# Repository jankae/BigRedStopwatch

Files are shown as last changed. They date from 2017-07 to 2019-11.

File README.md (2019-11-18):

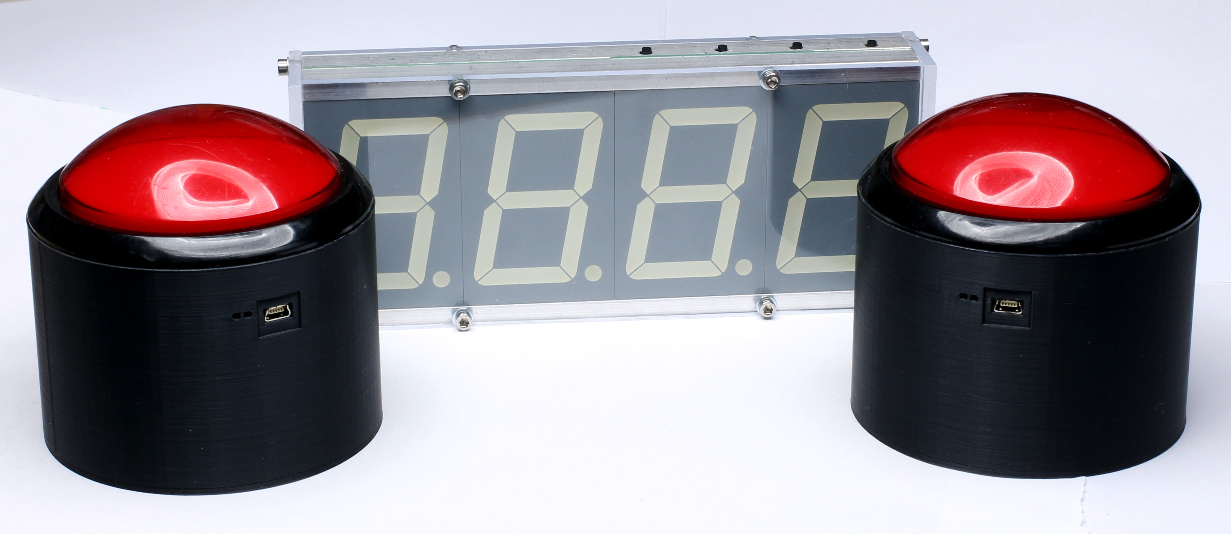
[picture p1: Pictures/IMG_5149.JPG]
Stopwatch

# What is it?
* A huge stopwatch with two big red control buttons (start and stop)
* Mainly intended for measuring time on an obstacle course

# How does it work?
* Each button and the display contain a radio module (RFM69)
* Button presses are send to the display which calculates the time

# Further features
* USB charging of the integrated LiPo batteries
* Retransmissions with time compensation if a radio packet gets lost
* Simple highscore management

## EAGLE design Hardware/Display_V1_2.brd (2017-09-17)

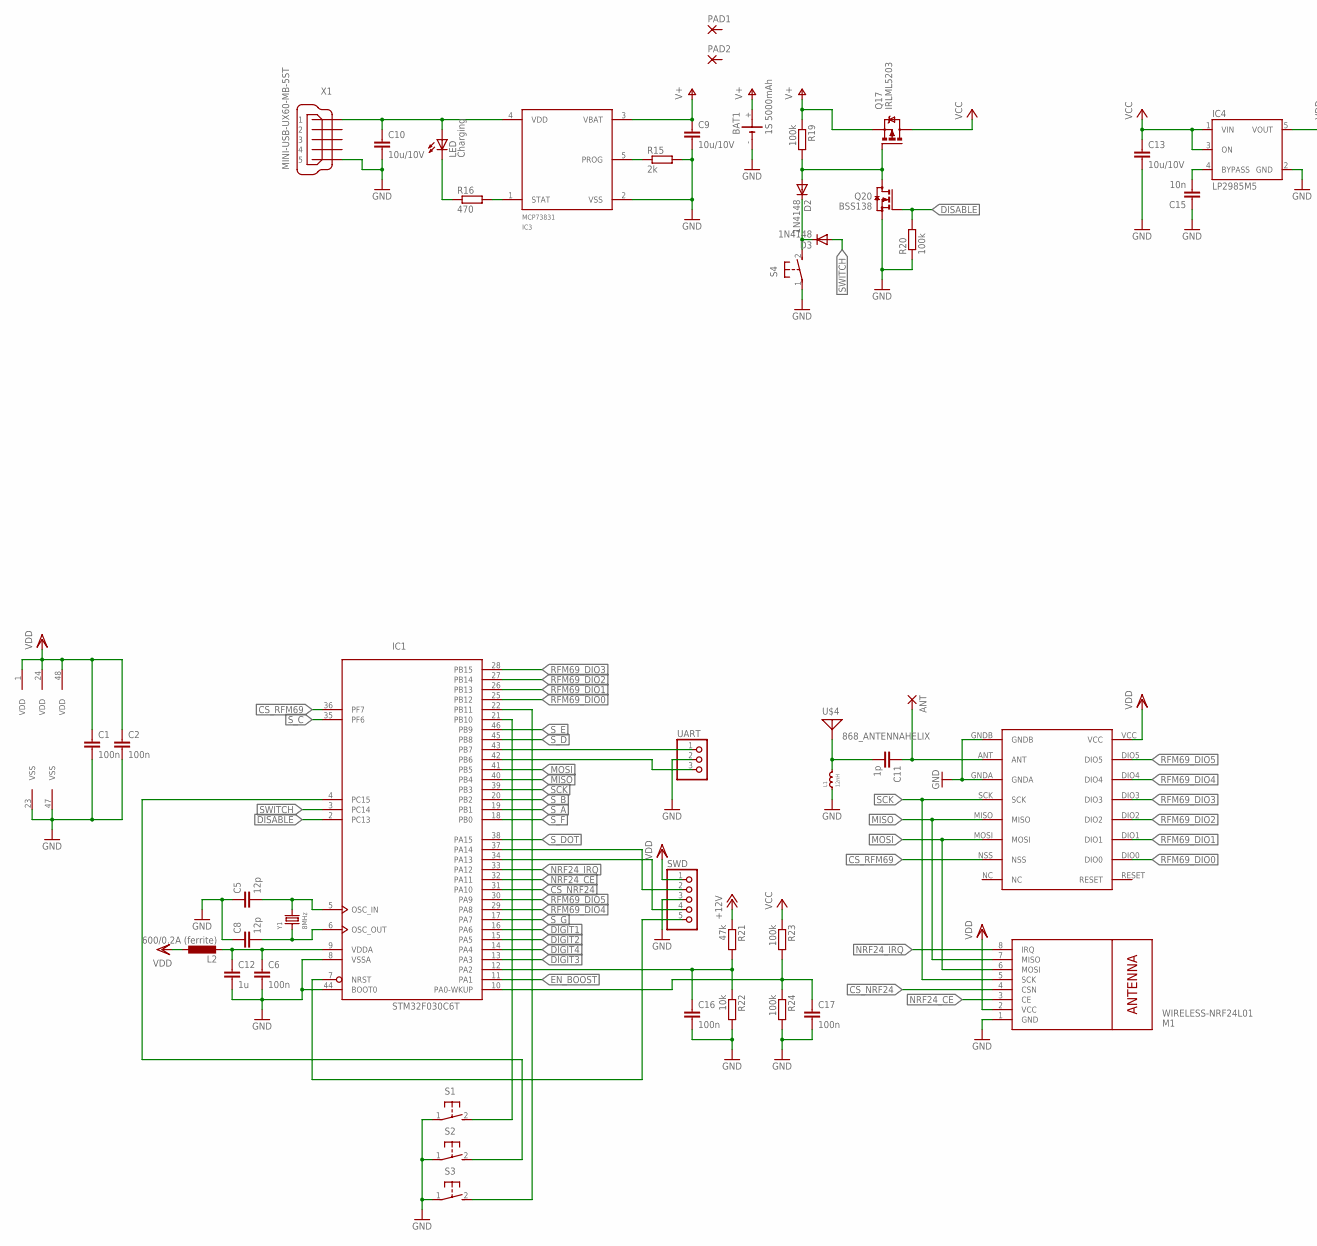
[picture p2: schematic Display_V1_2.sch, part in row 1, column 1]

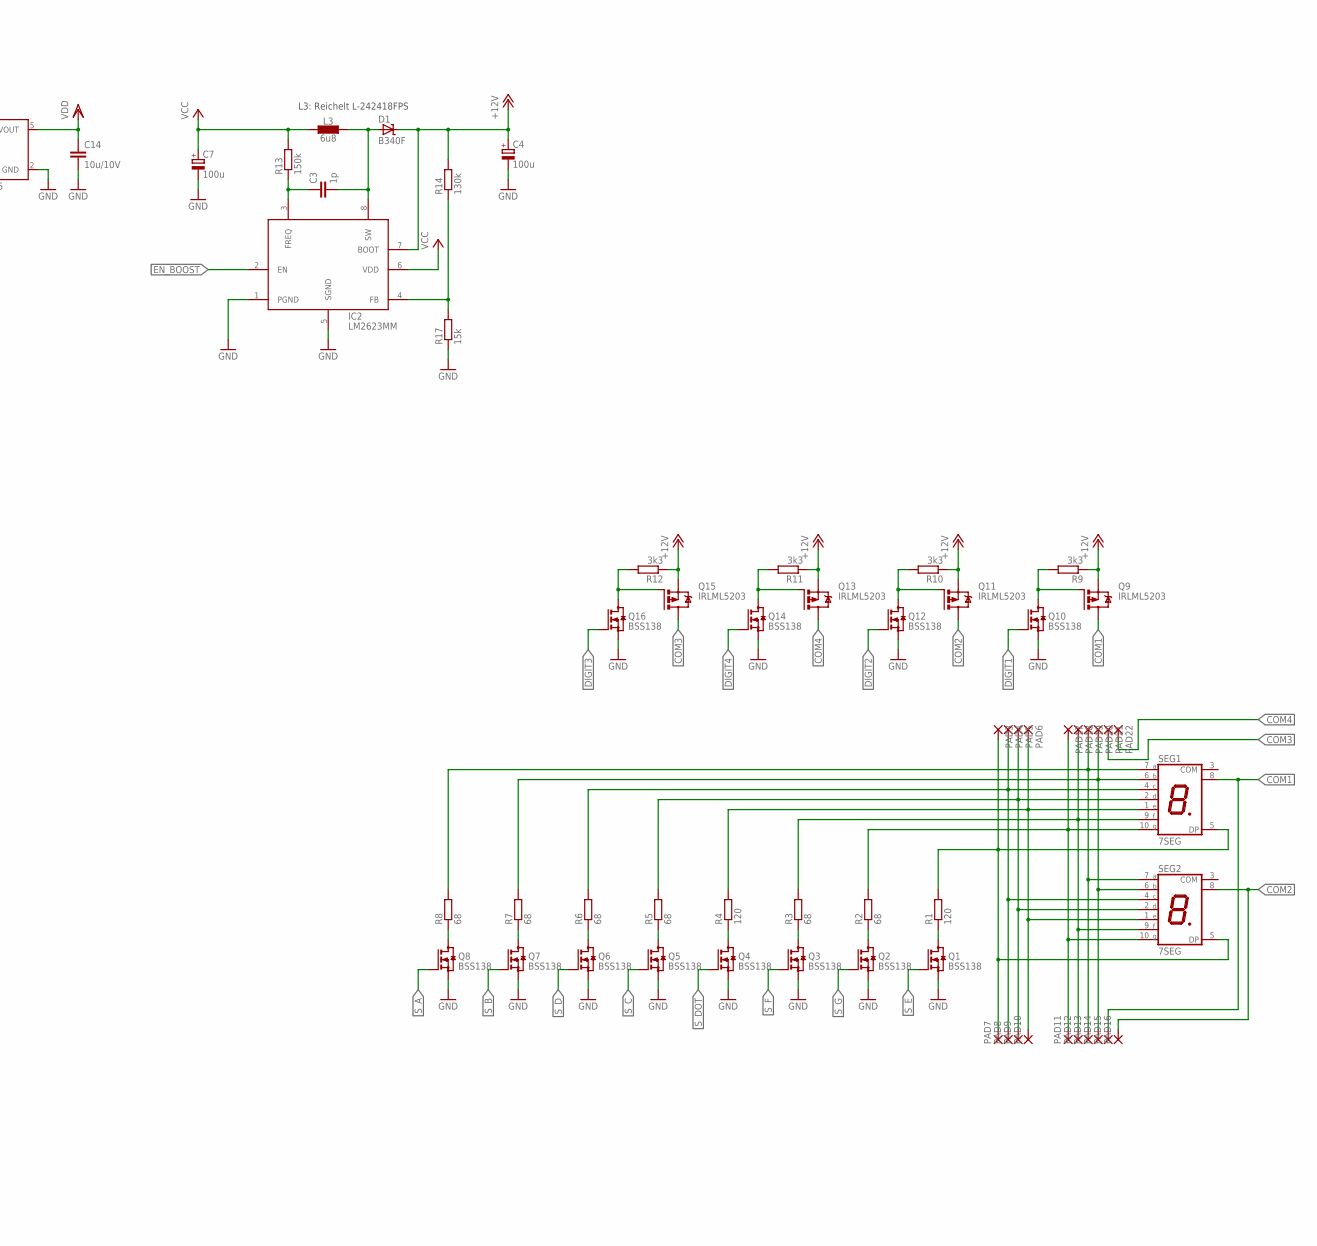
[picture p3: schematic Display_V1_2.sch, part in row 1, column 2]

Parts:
ANT: 1,6/0,8
BAT1: 1S 5000mAh; 1S_5000MAH
C1, C2: 100n; C0603K
C3, C11: 1p; C0603
C4, C7: 100u; 153CLV-0605
C5, C8: 12p; C0603
C6, C16, C17: 100n; C0603
C9, C10, C13, C14: 10u/10V; C1206
C12: 1u; C0603
C15: 10n; C0603
D1: B340F; SMC
D2, D3: 1N4148; MINIMELF
IC1: STM32F030C6T; LQFP48
IC2: LM2623MM; MSOP08
IC3: MCP73831; SOT23-5
IC4: LP2985M5; SOT23-5
L1: 12nH; 0603
L2: 600/0.2A (ferrite); L2012C
L3: 6u8; L_NR60XX
LED: Charging; CHIPLED_0603
M1: WIRELESS-NRF24L01
PAD1, PAD2: 2,54/1,0
PAD3, PAD4, PAD5, PAD6, PAD7, PAD8, PAD9, PAD10, PAD11, PAD12, PAD13, PAD14, PAD15, PAD16, PAD17, PAD18, PAD19, PAD20, PAD21, PAD22: SMD2; SMD1,27-2,54
Q1, Q2, Q3, Q4, Q5, Q6, Q7, Q8, Q10, Q12, Q14, Q16, Q20: BSS138; SOT23
Q9, Q11, Q13, Q15, Q17: IRLML5203; MICRO3
R1, R4: 120; R1206
R2, R3, R5, R6, R7, R8: 68; R1206
R9, R10, R11, R12: 3k3; R0603
R13: 150k; R0603
R14: 130k; R0603
R15: 2k; R0603
R16: 470; R0603
R17: 15k; R0603
R19, R20, R23, R24: 100k; R0603
R21: 47k; R0603
R22: 10k; R0603
S1, S2, S3, S4: 31-XX; B3F-31XX
SEG1, SEG2: 7SEG; 7SEG_70*40
SWD: PINHD-1X5; 1X05
U$1: RFM69HW; RFM
U$4: 868_ANTENNAHELIX; HELIX_868
UART: PINHD-1X3; 1X03
X1: MINI-USB-UX60-MB-5ST; UX60-MB-5ST
Y1: 8MHz; 3.2X2.5MM

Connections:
+12V: C4.+, D1.C, IC2.7 (BOOT), Q9.2 (S), Q11.2 (S), Q13.2 (S), Q15.2 (S), R9.1, R10.1, R11.1, R12.1, R14.2, R21.1
COM1: PAD15.1, Q9.3 (D), SEG1.8 (COM)
COM2: PAD16.1, Q11.3 (D), SEG2.8 (COM)
COM3: PAD21.1, Q15.3 (D)
COM4: PAD22.1, Q13.3 (D)
CS_NRF24: IC1.31 (PA10), M1.4 (CSN)
CS_RFM69: IC1.36 (PF7), U$1.NSS
DIGIT1: IC1.16 (PA6), Q10.1 (G)
DIGIT2: IC1.15 (PA5), Q12.1 (G)
DIGIT3: IC1.13 (PA3), Q16.1 (G)
DIGIT4: IC1.14 (PA4), Q14.1 (G)
DISABLE: IC1.2 (PC13), Q20.1 (G), R20.2
DP: PAD6.1, PAD10.1, R4.2, SEG1.1 (E), SEG2.1 (E)
EN_BOOST: IC1.11 (PA1), IC2.2 (EN)
GND: BAT1.-, C1.2, C2.2, C4.-, C5.1, C6.2, C7.-, C8.1, C9.2, C10.2, C12.2, C13.2, C14.2, C15.1, C16.2, C17.2, IC1.8 (VSSA), IC1.23 (VSS), IC1.44 (BOOT0), IC1.47 (VSS), IC2.1 (PGND), IC2.5 (SGND), IC3.2 (VSS), IC4.2 (GND), L1.1, M1.1 (GND), Q1.2 (S), Q2.2 (S), Q3.2 (S), Q4.2 (S), Q5.2 (S), Q6.2 (S), Q7.2 (S), Q8.2 (S), Q10.2 (S), Q12.2 (S), Q14.2 (S), Q16.2 (S), Q20.2 (S), R15.2, R17.1, R20.1, R22.2, R24.2, S1.1, S2.1, S3.1, S4.1, SWD.3, U$1.GNDA, U$1.GNDB, UART.2, X1.5
MISO: IC1.40 (PB4), M1.7 (MISO), U$1.MISO
MOSI: IC1.41 (PB5), M1.6 (MOSI), U$1.MOSI
unnamed: Q1.3 (D), R1.1
unnamed: Q2.3 (D), R2.1
unnamed: Q3.3 (D), R3.1
unnamed: Q4.3 (D), R4.1
unnamed: Q5.3 (D), R5.1
unnamed: Q6.3 (D), R6.1
unnamed: Q7.3 (D), R7.1
unnamed: Q8.3 (D), R8.1
unnamed: Q9.1 (G), Q10.3 (D), R9.2
unnamed: Q11.1 (G), Q12.3 (D), R10.2
unnamed: Q13.1 (G), Q14.3 (D), R11.2
unnamed: Q15.1 (G), Q16.3 (D), R12.2
unnamed: IC1.21 (PB10), S1.2 (S)
unnamed: C3.1, IC2.3 (FREQ), R13.1
unnamed: C5.2, IC1.5 (OSC_IN), Y1.3 (2)
unnamed: IC1.4 (PC15), S2.2 (S)
unnamed: IC1.22 (PB11), S3.2 (S)
unnamed: C8.2, IC1.6 (OSC_OUT), Y1.1
unnamed: IC3.5 (PROG), R15.1
unnamed: IC3.1 (STAT), R16.2
unnamed: LED.C, R16.1
unnamed: C3.2, D1.A, IC2.8 (SW), L3.2
unnamed: ANT.1, C11.1, U$1.ANT
unnamed: C11.2, L1.2, U$4.ANT, U$4.P$2, U$4.P$3, U$4.P$4, U$4.P$5, U$4.P$6, U$4.P$7, U$4.P$8, U$4.P$9, U$4.P$10, U$4.P$11, U$4.P$12, U$4.P$13, U$4.P$14, U$4.P$15, U$4.P$16, U$4.P$17, U$4.P$18, U$4.P$19, U$4.P$20
unnamed: IC2.4 (FB), R14.1, R17.2
unnamed: D2.A, Q17.1 (G), Q20.3 (D), R19.2
unnamed: C16.1, IC1.12 (PA2), R21.2, R22.1
unnamed: C15.2, IC4.4 (BYPASS)
unnamed: C17.1, IC1.10 (PA0-WKUP), R23.2, R24.1
NRF24_CE: IC1.32 (PA11), M1.3 (CE)
NRF24_IRQ: IC1.33 (PA12), M1.8 (IRQ)
NRST: IC1.7 (NRST), SWD.5
RFM69_DIO0: IC1.25 (PB12), U$1.DIO0
RFM69_DIO1: IC1.26 (PB13), U$1.DIO1
RFM69_DIO2: IC1.27 (PB14), U$1.DIO2
RFM69_DIO3: IC1.28 (PB15), U$1.DIO3
RFM69_DIO4: IC1.29 (PA8), U$1.DIO4
RFM69_DIO5: IC1.30 (PA9), U$1.DIO5
RX: IC1.43 (PB7), UART.1
SCK: IC1.39 (PB3), M1.5 (SCK), U$1.SCK
SEG_A: PAD13.1, PAD19.1, R8.2, SEG1.7 (A), SEG2.7 (A)
SEG_B: PAD14.1, PAD20.1, R7.2, SEG1.6 (B), SEG2.6 (B)
SEG_C: PAD5.1, PAD9.1, R5.2, SEG1.2 (D), SEG2.2 (D)
SEG_D: PAD4.1, PAD8.1, R6.2, SEG1.4 (C), SEG2.4 (C)
SEG_E: PAD3.1, PAD7.1, R1.2, SEG1.5 (DP), SEG2.5 (DP)
SEG_F: PAD12.1, PAD18.1, R3.2, SEG1.9 (F), SEG2.9 (F)
SEG_G: PAD11.1, PAD17.1, R2.2, SEG1.10 (G), SEG2.10 (G)
SWCLK: IC1.37 (PA14), SWD.2
SWDIO: IC1.34 (PA13), SWD.4
SWITCH: D3.A, IC1.3 (PC14)
S_A: IC1.19 (PB1), Q8.1 (G)
S_B: IC1.20 (PB2), Q7.1 (G)
S_C: IC1.35 (PF6), Q5.1 (G)
S_D: IC1.45 (PB8), Q6.1 (G)
S_DOT: IC1.38 (PA15), Q4.1 (G)
S_E: IC1.46 (PB9), Q1.1 (G)
S_F: IC1.18 (PB0), Q3.1 (G)
S_G: IC1.17 (PA7), Q2.1 (G)
TX: IC1.42 (PB6), UART.3
V+: BAT1.+, C9.1, IC3.3 (VBAT), Q17.2 (S), R19.1
VCC: C7.+, C13.1, IC2.6 (VDD), IC4.1 (VIN), IC4.3 (ON), L3.1, Q17.3 (D), R13.2, R23.1
VDD: C1.1, C2.1, C14.1, IC1.1 (VDD), IC1.24 (VDD), IC1.48 (VDD), IC4.5 (VOUT), L2.1, M1.2 (VCC), SWD.1, U$1.VCC
VDDA: C6.1, C12.1, IC1.9 (VDDA), L2.2
VIN: C10.1, IC3.4 (VDD), LED.A, X1.1
_SWITCH: D2.C, D3.C, S4.2 (S)

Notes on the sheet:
L3: Reichelt L-242418FPS

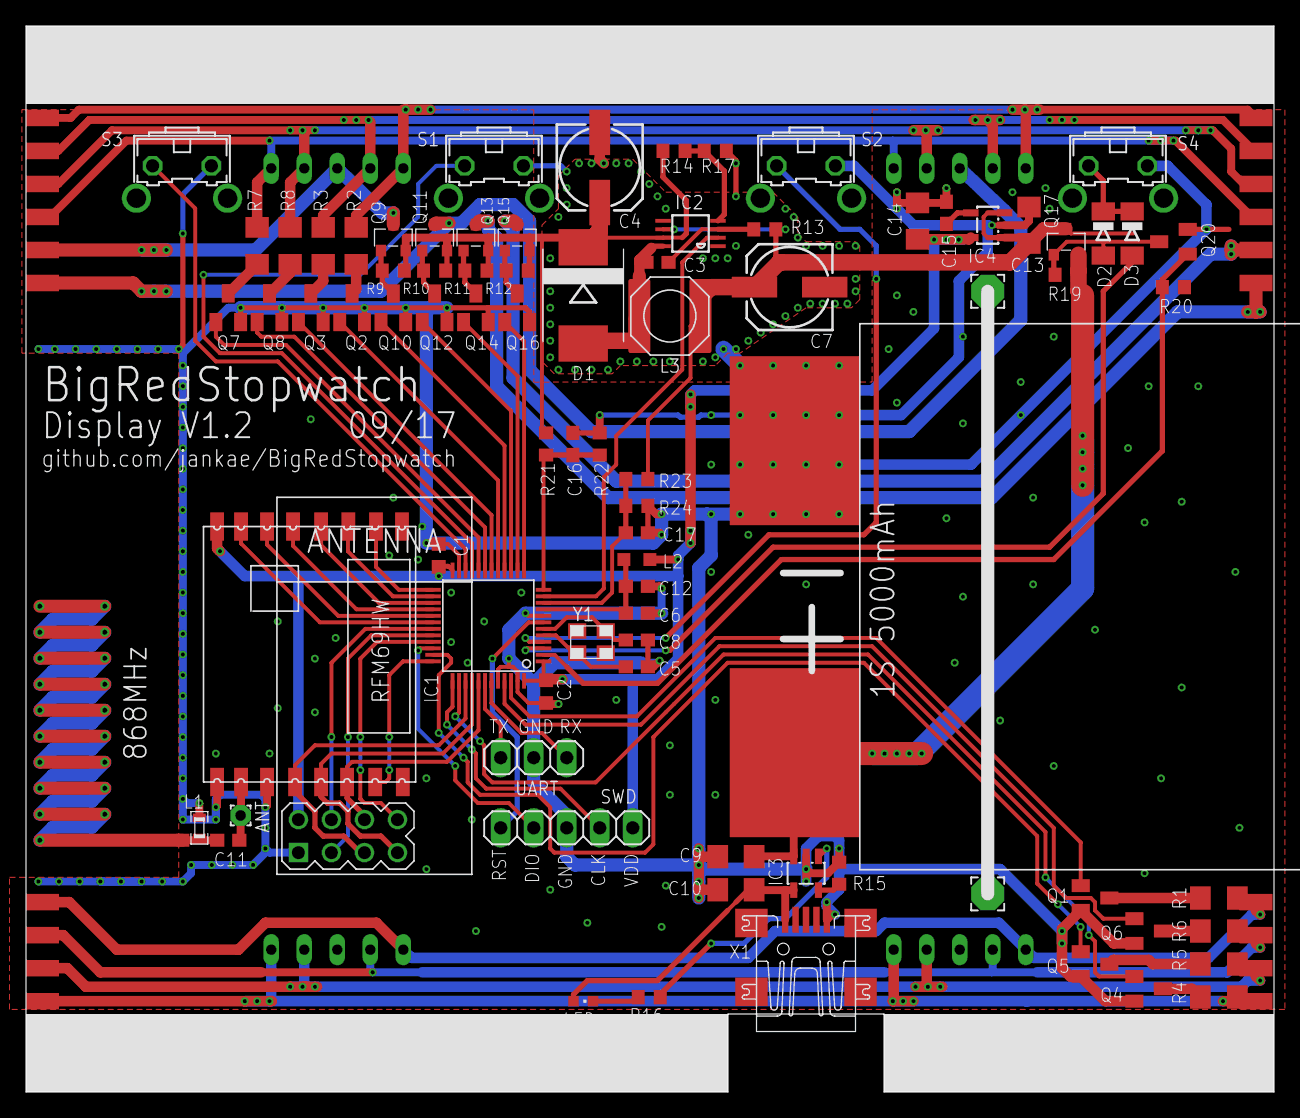
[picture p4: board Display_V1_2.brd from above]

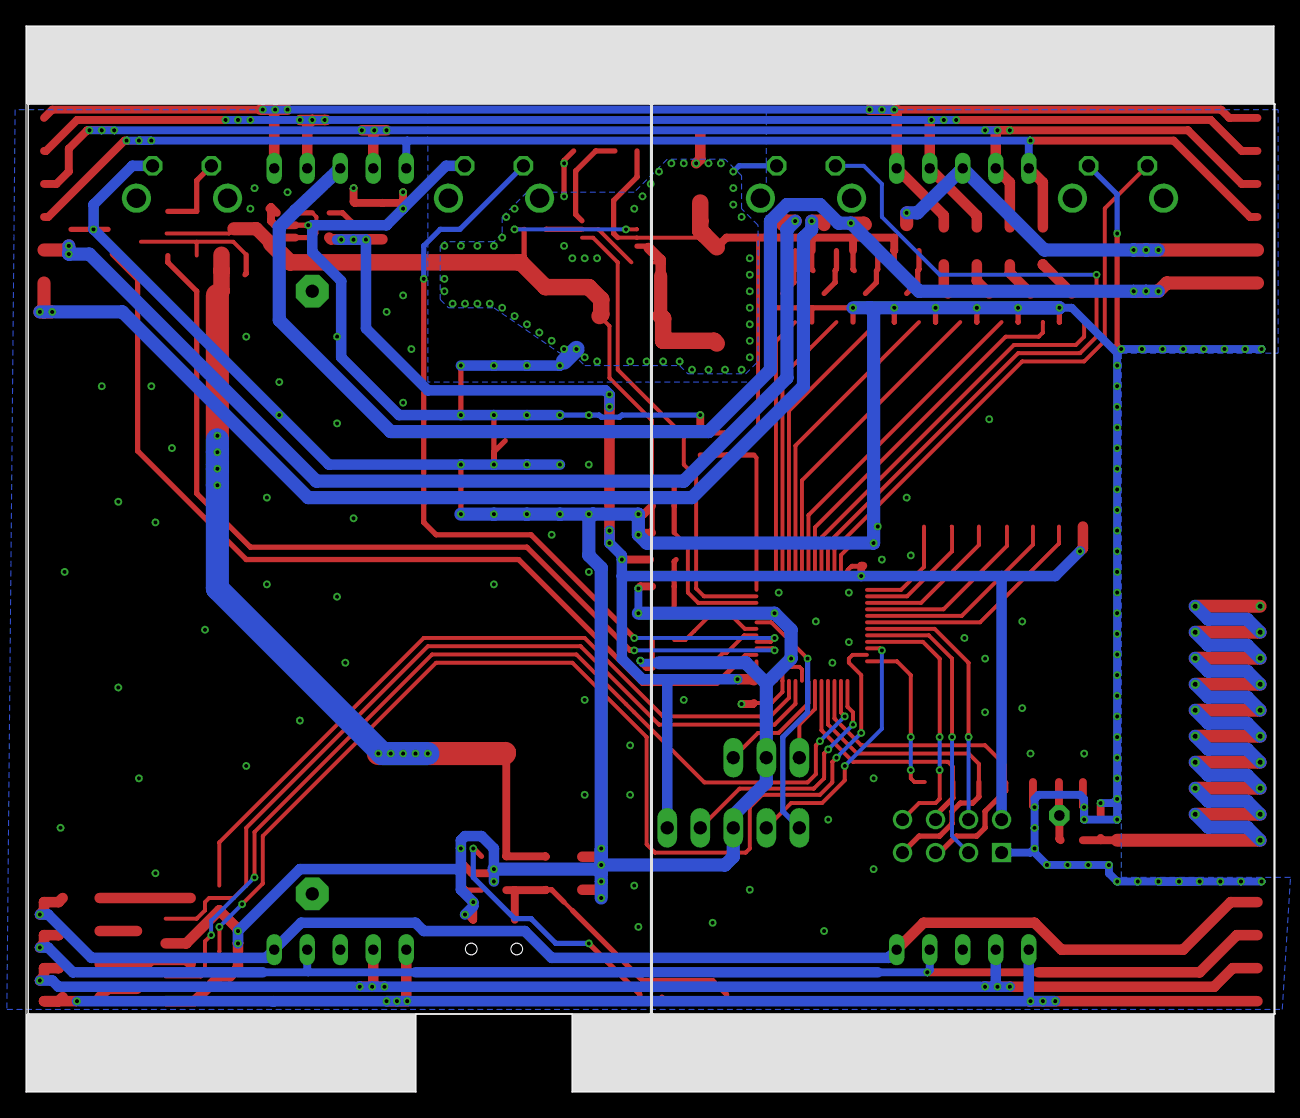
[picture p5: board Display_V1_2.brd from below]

Board: 2 copper layers, 96.0 x 82.0 mm, 106 parts (2 on the bottom side), 82 nets.

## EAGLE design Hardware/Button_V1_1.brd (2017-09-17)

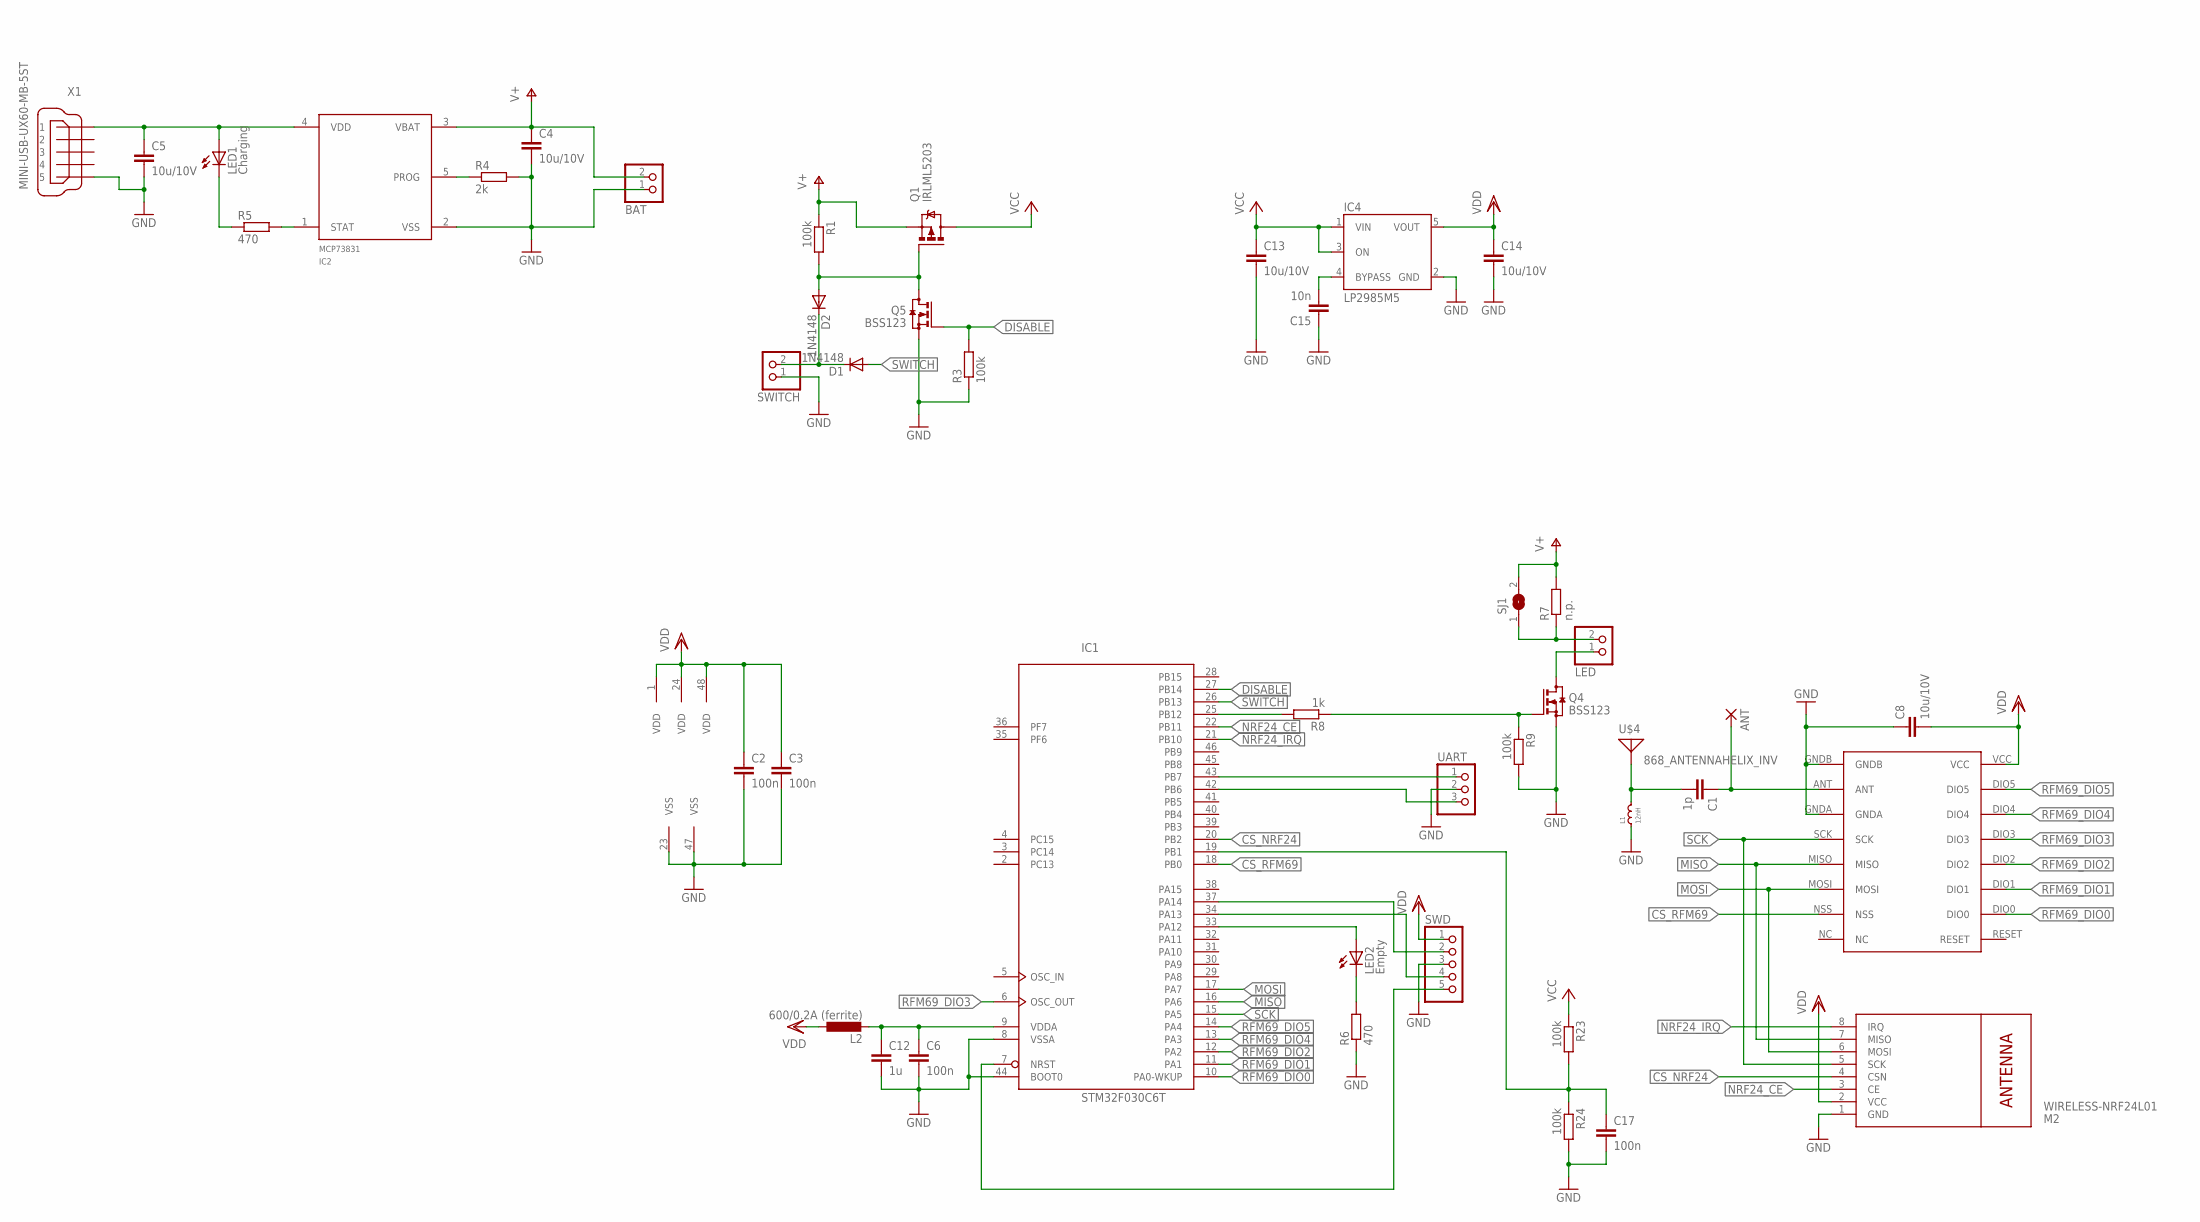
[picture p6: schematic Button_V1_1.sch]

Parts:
ANT: 1,6/0,8
BAT: PINHD-1X2; 1X02
C1: 1p; C0603
C2, C3, C6, C17: 100n; C0603
C4, C5, C8, C13, C14: 10u/10V; C1206
C12: 1u; C0603
C15: 10n; C0603
D1, D2: 1N4148; SOD323-W
IC1: STM32F030C6T; LQFP48
IC2: MCP73831; SOT23-5
IC4: LP2985M5; SOT23-5
L1: 12nH; 0603
L2: 600/0.2A (ferrite); L2012C
LED: PINHD-1X2; 1X02
LED1: Charging; CHIPLED_0603
LED2: Empty; CHIPLED_0603
M2: WIRELESS-NRF24L01
Q1: IRLML5203; MICRO3
Q4, Q5: BSS123; SOT23
R1, R3, R9, R23, R24: 100k; R0603
R4: 2k; R0603
R5, R6: 470; R0603
R7: n.p.; R1206
R8: 1k; R0603
SJ1: SJ
SWD: PINHD-1X5; 1X05
SWITCH: PINHD-1X2; 1X02
U$1: RFM69HW; RFM
U$4: 868_ANTENNAHELIX_INV; HELIX_868_INV
UART: PINHD-1X3; 1X03
X1: MINI-USB-UX60-MB-5ST; UX60-MB-5ST

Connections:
CS_NRF24: IC1.20 (PB2), M2.4 (CSN)
CS_RFM69: IC1.18 (PB0), U$1.NSS
DISABLE: IC1.27 (PB14), Q5.1 (G), R3.2
GND: BAT.1, C2.2, C3.2, C4.2, C5.2, C6.2, C8.1, C12.2, C13.2, C14.2, C15.1, C17.2, IC1.8 (VSSA), IC1.23 (VSS), IC1.44 (BOOT0), IC1.47 (VSS), IC2.2 (VSS), IC4.2 (GND), L1.1, M2.1 (GND), Q4.2 (S), Q5.2 (S), R3.1, R4.2, R6.1, R9.2, R24.2, SWD.3, SWITCH.1, U$1.GNDA, U$1.GNDB, UART.2, X1.5
MISO: IC1.16 (PA6), M2.7 (MISO), U$1.MISO
MOSI: IC1.17 (PA7), M2.6 (MOSI), U$1.MOSI
unnamed: D2.A, Q1.1 (G), Q5.3 (D), R1.2
unnamed: IC2.5 (PROG), R4.1
unnamed: ANT.1, C1.1, U$1.ANT
unnamed: C1.2, L1.2, U$4.ANT, U$4.P$2, U$4.P$3, U$4.P$4, U$4.P$5, U$4.P$6, U$4.P$7, U$4.P$8, U$4.P$9, U$4.P$10, U$4.P$11, U$4.P$12, U$4.P$13, U$4.P$14, U$4.P$15, U$4.P$16, U$4.P$17, U$4.P$18, U$4.P$19, U$4.P$20
unnamed: LED2.C, R6.2
unnamed: IC2.1 (STAT), R5.2
unnamed: IC1.33 (PA12), LED2.A
unnamed: LED1.C, R5.1
unnamed: LED.1, Q4.3 (D)
unnamed: LED.2, R7.1, SJ1.1
unnamed: Q4.1 (G), R8.1, R9.1
unnamed: IC1.25 (PB12), R8.2
unnamed: C15.2, IC4.4 (BYPASS)
unnamed: C17.1, IC1.19 (PB1), R23.2, R24.1
NRF24_CE: IC1.22 (PB11), M2.3 (CE)
NRF24_IRQ: IC1.21 (PB10), M2.8 (IRQ)
NRST: IC1.7 (NRST), SWD.5
RFM69_DIO0: IC1.10 (PA0-WKUP), U$1.DIO0
RFM69_DIO1: IC1.11 (PA1), U$1.DIO1
RFM69_DIO2: IC1.12 (PA2), U$1.DIO2
RFM69_DIO3: IC1.6 (OSC_OUT), U$1.DIO3
RFM69_DIO4: IC1.13 (PA3), U$1.DIO4
RFM69_DIO5: IC1.14 (PA4), U$1.DIO5
RX: IC1.43 (PB7), UART.1
SCK: IC1.15 (PA5), M2.5 (SCK), U$1.SCK
SWCLK: IC1.37 (PA14), SWD.2
SWDIO: IC1.34 (PA13), SWD.4
SWITCH: D1.A, IC1.26 (PB13)
TX: IC1.42 (PB6), UART.3
V+: BAT.2, C4.1, IC2.3 (VBAT), Q1.2 (S), R1.1, R7.2, SJ1.2
VCC: C13.1, IC4.1 (VIN), IC4.3 (ON), Q1.3 (D), R23.1
VDD: C2.1, C3.1, C8.2, C14.1, IC1.1 (VDD), IC1.24 (VDD), IC1.48 (VDD), IC4.5 (VOUT), L2.1, M2.2 (VCC), SWD.1, U$1.VCC
VDDA: C6.1, C12.1, IC1.9 (VDDA), L2.2
VIN: C5.1, IC2.4 (VDD), LED1.A, X1.1
_SWITCH: D1.C, D2.C, SWITCH.2

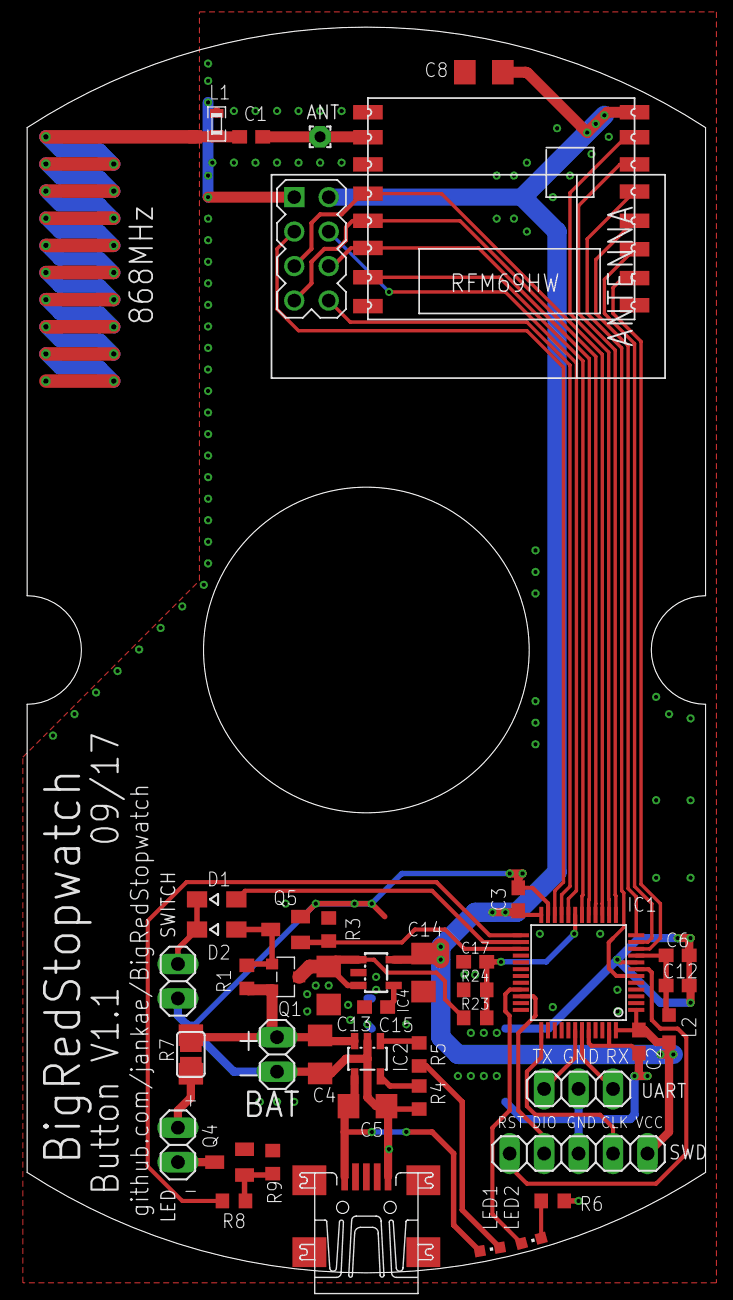
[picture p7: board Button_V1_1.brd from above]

Board: 2 copper layers, 50.0 x 91.8 mm, 45 parts (0 on the bottom side), 41 nets.

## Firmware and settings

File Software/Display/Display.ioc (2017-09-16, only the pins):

Mcu.UserName=STM32F030C8Tx
PA0.GPIO_Label=BATTERY_SENSE
PA0.Signal=ADC_IN0
PA1.GPIO_Label=BOOST_ENABLE
PA1.Signal=GPIO_Output
PA10.GPIO_Label=CS_NRF24
PA10.Signal=GPIO_Output
PA11.GPIO_Label=NRF24_CE
PA11.Signal=GPIO_Output
PA12.GPIO_Label=NRF24_IRQ
PA12.Signal=GPIO_Input
PA15.GPIO_Label=SEGMENT_DOT
PA15.Signal=GPIO_Output
PA2.GPIO_Label=BOOST_SENSE
PA2.Signal=ADC_IN2
PA3.GPIO_Label=DIGIT3
PA3.Signal=GPIO_Output
PA4.GPIO_Label=DIGIT4
PA4.Signal=GPIO_Output
PA5.GPIO_Label=DIGIT2
PA5.Signal=GPIO_Output
PA6.GPIO_Label=DIGIT1
PA6.Signal=GPIO_Output
PA7.GPIO_Label=SEGMENT_G
PA7.Signal=GPIO_Output
PA8.GPIO_Label=RFM69_DIO4
PA8.Signal=GPIO_Input
PA9.GPIO_Label=RFM69_DIO5
PA9.Signal=GPIO_Input
PB0.GPIO_Label=SEGMENT_F
PB0.Signal=GPIO_Output
PB1.GPIO_Label=SEGMENT_A
PB1.Signal=GPIO_Output
PB10.GPIO_Label=SWITCH1
PB10.Signal=GPIO_Input
PB11.GPIO_Label=SWITCH3
PB11.Signal=GPIO_Input
PB12.GPIO_Label=RFM69_DIO0
PB12.Signal=GPXTI12
PB13.GPIO_Label=RFM69_DIO1
PB13.Signal=GPIO_Input
PB14.GPIO_Label=RFM69_DIO2
PB14.Signal=GPIO_Input
PB15.GPIO_Label=RFM69_DIO3
PB15.Signal=GPIO_Input
PB2.GPIO_Label=SEGMENT_B
PB2.Signal=GPIO_Output
PB3.Signal=SPI1_SCK
PB4.Signal=SPI1_MISO
PB5.Signal=SPI1_MOSI
PB6.Signal=USART1_TX
PB7.Signal=USART1_RX
PB8.GPIO_Label=SEGMENT_D
PB8.Signal=GPIO_Output
PB9.GPIO_Label=SEGMENT_E
PB9.Signal=GPIO_Output
PC13.GPIO_Label=DISABLE
PC13.Signal=GPIO_Output
PC14-OSC32_IN.GPIO_Label=SWITCH_ONOFF
PC14-OSC32_IN.Signal=GPIO_Input
PC15-OSC32_OUT.GPIO_Label=SWITCH2
PC15-OSC32_OUT.Signal=GPIO_Input
PF0-OSC_IN.Signal=RCC_OSC_IN
PF1-OSC_OUT.Signal=RCC_OSC_OUT
PF6.GPIO_Label=SEGMENT_C
PF6.Signal=GPIO_Output
PF7.GPIO_Label=CS_RFM69
PF7.Signal=GPIO_Output

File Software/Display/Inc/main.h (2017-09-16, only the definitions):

#define DISABLE_Pin GPIO_PIN_13
#define DISABLE_GPIO_Port GPIOC
#define SWITCH_ONOFF_Pin GPIO_PIN_14
#define SWITCH_ONOFF_GPIO_Port GPIOC
#define SWITCH2_Pin GPIO_PIN_15
#define SWITCH2_GPIO_Port GPIOC
#define BATTERY_SENSE_Pin GPIO_PIN_0
#define BATTERY_SENSE_GPIO_Port GPIOA
#define BOOST_ENABLE_Pin GPIO_PIN_1
#define BOOST_ENABLE_GPIO_Port GPIOA
#define BOOST_SENSE_Pin GPIO_PIN_2
#define BOOST_SENSE_GPIO_Port GPIOA
#define DIGIT3_Pin GPIO_PIN_3
#define DIGIT3_GPIO_Port GPIOA
#define DIGIT4_Pin GPIO_PIN_4
#define DIGIT4_GPIO_Port GPIOA
#define DIGIT2_Pin GPIO_PIN_5
#define DIGIT2_GPIO_Port GPIOA
#define DIGIT1_Pin GPIO_PIN_6
#define DIGIT1_GPIO_Port GPIOA
#define SEGMENT_G_Pin GPIO_PIN_7
#define SEGMENT_G_GPIO_Port GPIOA
#define SEGMENT_F_Pin GPIO_PIN_0
#define SEGMENT_F_GPIO_Port GPIOB
#define SEGMENT_A_Pin GPIO_PIN_1
#define SEGMENT_A_GPIO_Port GPIOB
#define SEGMENT_B_Pin GPIO_PIN_2
#define SEGMENT_B_GPIO_Port GPIOB
#define SWITCH1_Pin GPIO_PIN_10
#define SWITCH1_GPIO_Port GPIOB
#define SWITCH3_Pin GPIO_PIN_11
#define SWITCH3_GPIO_Port GPIOB
#define RFM69_DIO0_Pin GPIO_PIN_12
#define RFM69_DIO0_GPIO_Port GPIOB
#define RFM69_DIO0_EXTI_IRQn EXTI4_15_IRQn
#define RFM69_DIO1_Pin GPIO_PIN_13
#define RFM69_DIO1_GPIO_Port GPIOB
#define RFM69_DIO2_Pin GPIO_PIN_14
#define RFM69_DIO2_GPIO_Port GPIOB
#define RFM69_DIO3_Pin GPIO_PIN_15
#define RFM69_DIO3_GPIO_Port GPIOB
#define RFM69_DIO4_Pin GPIO_PIN_8
#define RFM69_DIO4_GPIO_Port GPIOA
#define RFM69_DIO5_Pin GPIO_PIN_9
#define RFM69_DIO5_GPIO_Port GPIOA
#define CS_NRF24_Pin GPIO_PIN_10
#define CS_NRF24_GPIO_Port GPIOA
#define NRF24_CE_Pin GPIO_PIN_11
#define NRF24_CE_GPIO_Port GPIOA
#define NRF24_IRQ_Pin GPIO_PIN_12
#define NRF24_IRQ_GPIO_Port GPIOA
#define SEGMENT_C_Pin GPIO_PIN_6
#define SEGMENT_C_GPIO_Port GPIOF
#define CS_RFM69_Pin GPIO_PIN_7
#define CS_RFM69_GPIO_Port GPIOF
#define SEGMENT_DOT_Pin GPIO_PIN_15
#define SEGMENT_DOT_GPIO_Port GPIOA
#define SEGMENT_D_Pin GPIO_PIN_8
#define SEGMENT_D_GPIO_Port GPIOB
#define SEGMENT_E_Pin GPIO_PIN_9
#define SEGMENT_E_GPIO_Port GPIOB

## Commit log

2017-07-21 Display template + initial Hard+Software
    [Button.sch, Display.brd, Display.sch]
2017-07-25 Further software (Switches, HAL)
    [Display.brd]
2017-07-29 Added crystal to display board
    [Button.sch, Display.brd, Display.sch]
2017-07-29 Button Layout done
    [Button.brd, Button.sch]
2017-07-29 Initial CubeMX button
2017-07-29 LED output added to button
    [Button.brd, Button.sch]
2017-07-30 Second iteration of display board
    [Button.brd, Button.sch, Display.brd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]
2017-08-01 3V LDO + voltage sensing
    [Button.brd, Button.sch]
2017-08-01 last(?) changes
    [Display_V1_1.brd, Display_V1_1.sch]
2017-08-10 Final PCB changes
    [Display_V1_1.brd, Display_V1_1.sch]
2017-09-03 Slight changes for easier fabrication
    [Display_V1_1.brd, Display_V1_1.sch]
2017-09-03 Untested firmware of button
2017-09-03 pass switch number instead of switch
2017-09-12 Battery and system fault handling
2017-09-16 Bugfixes and improvements, basic system working
    [Display_V1_1.brd, Display_V1_1.sch]
2017-09-17 Auto-turnoff + display battery voltage at startup
2017-09-17 New board revisions (Supply fixes)
    [Button_V1_1.brd, Button_V1_1.sch, Display_V1_2.brd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]
2019-07-10 Eagle version update
    [Button_V1_1.sch]

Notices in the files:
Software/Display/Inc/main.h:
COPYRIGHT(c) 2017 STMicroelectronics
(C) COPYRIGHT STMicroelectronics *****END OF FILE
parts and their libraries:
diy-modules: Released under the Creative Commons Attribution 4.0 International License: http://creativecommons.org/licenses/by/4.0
